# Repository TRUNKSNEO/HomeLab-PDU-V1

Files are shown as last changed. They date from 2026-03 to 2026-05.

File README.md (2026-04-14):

<div align="center">
  Shrike Lab logo
  
  [Website](https://www.shrikelab.co) | [YouTube](https://www.youtube.com/@ShrikeLab)
  
</div>
<p align="center">
  <a href="https://patreon.com/shrikelab">
    
  </a>
  <a href="https://ko-fi.com/shrikelab">
    
  </a>
</p>

# **ShrikeLab PDU V1** - 5 & 10 port USB-C PDUs for 10" and 19" racks
These PSUs are power delivery solutions for micro PC clusters and homelabs that suits either 10" and 19" racks. All variants are built around a Meanwell HRP-300-24 featuring either 5 or 10 USB-C power delivery ports enclosed in sheet metal or 3D printed ABS/ASA housings. 

<div align="center">
  <a
    href="https://www.Shrikelab.co" title="Kits and PCBs available now!">Kits and PCBs available now!
  </a>  
</div>

---

<p float="center">
   
</p>

Mini and micro labs are a great solution for homelabbing, but the power delivery options are often bulky and hard to manage due to the need for an individual power brick per computer.
This project helps fix this by consolidating power delivery for up to 10 65W micro PCs into a single unit that fits in either a 10" or 19" 1U rack. This differs from a conventional multi-port USB PD hub by not needing to re-negotiate any power delivery voltages when a unit is turned off or unplugged, or when the power load across ports changes drastically. Also the packaging is designed specifially for rack mounting, with active cooling and simple power switching.

[**Design and build video here**](https://www.youtube.com/watch?v=8tTG0TBM7ts)

[**Follow-up and testing video here**](https://www.youtube.com/watch?v=Ig7oZpujHtc&t)

<br>

### Features:
- Both 19" and 10" variants
- Up to 10 x 65W USB-C outputs
- 1U Height
- Active cooling
- Sheet metal housing or fully 3D printable
- All variants built around a Meanwell HRP-300-24
- All 3D printed parts fit on a 220x220mm print bed

<br>

### Repo Content:
- **Assembly** - Renders and references for main and sub-assemblies, plus bill of material for each variant
  - **CAD** - CAD files for all varients, universal files and drawings of components
    - **Universal** - Files thats are used for multiple variants
    - 10in_Single
    - 10in_Dual
    - 10in_3D_Modular
    - 10in_3D_Unibody
    - 19in_Single
    - 19in_Dual
    - 19in_Dual_SBS
    - **Blanks** - STP files for customisation
    - **Universal** - STL and STP files that are used for multiple variants
  - **Drawings** - Drawings of components and wiring
    - **Electrical** - Harness pinouts and drawings of electronic components
    -  **Hardware** - Drawings of hardware along with sheet metal engineering drawings
- **IMG** - Images
- **PCB** - PCB gerber manufacturing files

<br>

### Issues:
There's a lot of ground to cover with this repo, so if you find an issue, please raise it with the GitHub issue system and it will get fixed. If you have questions about assembly or any of the variants, please make sure you have read through all the readme content before reaching out to save on time.

### ToDo:
- Export all sheet metal STEP files in 1.2mm thickness for imperial
- Add 40mm fan guide and buck converter writeup

# Variants:
All variants are built around a Meanwell HRP-300-24 and the same PCB. The housings are designed to fit in 1U of space in either a 10in and 19in server rack. 

## 10 Inch - Single:
The original 10" enclosure, a sheet metal body + lid make up the housing, with a 3D printed front and rear. 5 outputs.
<p float="center">
   
</p>
<p float="center">
   
   
</p>

[Bill of materials](https://github.com/Shrike-Lab/MiniLab-PSU/blob/main/ASSEMBLY/README.md#10-inch---single)

<br>

## 10 Inch - 3D Printed - Unibody:
10" printed unibody enclosure, made to be as easy as possible with minimal additional hardware, with the trade-off of being a little harder to print. No inserts required, all bolts thread directly into the print material. Small hatch for attaching button + fan and connecting wiring to PCB.
<p float="center">
   
</p>
<p float="center">
   
   
</p>

[Bill of materials](https://github.com/Shrike-Lab/MiniLab-PSU/blob/main/ASSEMBLY/README.md#10-inch---3d-printed---unibody)

<br>

## 10 Inch - 3D Printed - Modular:
10" printed enclosure, made to be more modular and mod-friendly but requires more M3 inserts and bolts to assebmle. The CAD folder for this variant also includes 'flipped' front and rear STLs that have the mounting tabs swapped, so that the USB-C ports and power intput will face the front of the rack instead of the rear.
<p float="center">
   
</p>
<p float="center">
   
   
</p>

[Bill of materials](https://github.com/Shrike-Lab/MiniLab-PSU/blob/main/ASSEMBLY/README.md#10-inch---3d-printed---modular)

<br>

## 10 Inch - Dual:
10" enclosure for external PSU's. 10 outputs, intended for use with alternative power sources like battery or solar, or for up-cycling external 300W PSUs.
<p float="center">
   
</p>
<p float="center">
   
   
</p>

[Bill of materials](https://github.com/Shrike-Lab/MiniLab-PSU/blob/main/ASSEMBLY/README.md#10-inch---dual)

<br>

## 19 Inch - Single:
19" inch version of 5 output variant. Additional space could be used for cable / tiny-mini-micro storage.
<p float="center">
   
</p>
<p float="center">
   
   
</p>

[Bill of materials](https://github.com/Shrike-Lab/MiniLab-PSU/blob/main/ASSEMBLY/README.md#19-inch---single)

<br>

## 19 Inch - Dual:
19" with 10 outputs from 2 x internal assemblies.
<p float="center">
   
</p>
<p float="center">
   
   
</p>

[Bill of materials](https://github.com/Shrike-Lab/MiniLab-PSU/blob/main/ASSEMBLY/README.md#19-inch---dual)

<br>

## 19 Inch - SBS:
For people that couldn't possibly deal with a power input in the middle of the housing, this version has matching components side-by-side so inputs and outputs can be coordinated easier. One harness will require extending due to the layout.
<p float="center">
   
</p>
<p float="center">
   
   
</p>

[Bill of materials](https://github.com/Shrike-Lab/MiniLab-PSU/blob/main/ASSEMBLY/README.md#19-inch---dual---sbs)

<br>

# Disclaimer:
If you build, modify, or use this project, you do so entirely at your own risk. The author provides these files without any warranty or guarantee of safety, reliability, or fitness for any particular purpose, and accepts no liability for any damage, injury, loss, or other consequences resulting from their use.

# License:
This project is licensed under the Creative Commons Attribution-NonCommercial-ShareAlike 4.0 International License.

You may use, share, and modify the files in this repository for personal, non-commercial purposes, provided you give appropriate attribution and distribute any derivatives under the same license.

Commercial use is not permitted without separate written permission.

Editable source design files may not be provided; this repository may include manufacturing or export files only.

Learn more [here.](https://creativecommons.org/licenses/by-nc-sa/4.0/deed.en)

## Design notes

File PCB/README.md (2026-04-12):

# PCB:
All variants use the same 2 layer 1.6mm thick PCB. This folder contains production files that can be uploaded to a PCB service for manufacturing, JLCPCB is my go-to. PCB assembly is recommended unless you have capability to do SMD soldering with either a hot air station or reflow oven.
There is currently no option for a through-hole variant because the tranistor does not come in a TH package.

**Parameters for PCB manufacturing:**
- 2 Oz copper trace weight - This is a must for current rating
- 1.6mm PCB thickness

<br>

### PCB Notes:
- You can use either an LM2596S or and MP1584EN. Just move the mounting headers to the corresponding holes.
- Connectors J19, J20, J21, J22 are optional. Either used for additional power output, or testing.
- After assembly, set fan header output voltage **before** plugging any fans in.

<br>

### Power Delivery Modules:
THe board assembly contains 5 USB-C power delivery modules that are based on an XPM52C with the following power profiles.

12V/3A, 15V/3A, 20V/3.25A

**Low Power PDO:** 5V/3A, 9V/3A, 12V/2.5A, 20V/1.5A

**High Power PDO:** 5V/3A, 9V/3A, 12V/3A

There's an interesting article [here](https://mysku.club/blog/aliexpress/101076.html) (is in Russian so will need translating) that goes over the thermal performance of the power delivery chips at 65W.

<p float="center">
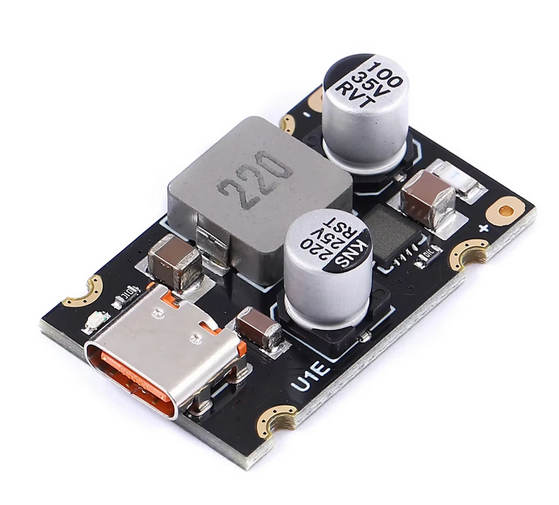
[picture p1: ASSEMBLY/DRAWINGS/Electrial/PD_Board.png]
   
</p>

### Buck Converter:
To power the 40mm chassis fans the main 24V rail needs to be stepped down to 12V. This can be done with either an LM2596S or MP1584EN, on the PCB there's header holes and labels for both. The LM2596S is much more popular, but the MP1584EN is newer and has less EMC. MP1584EN comes in multiple variants, **make sure to get the variable one so you're able to tune the fan voltage**.

<p float="center">
   
   
</p>

### Wiring:
There are two harnesses per set of internal electronics, one for main power and one for the button. The drawings can be found [here](https://github.com/Shrike-Lab/MiniLab-PSU/tree/main/ASSEMBLY/DRAWINGS/Electrial).

- **I would highly recommend you double check the pinout of your latching button before wiring it up, as they can differ from brand to brand.**

| Part | Harness | Quantity Per Assembly | Link |
| --- | --- | --- | --- |
| Ring spade | 24V Power | 9 | https://www.digikey.com/en/products/detail/molex/0193240008/3884473 |
| PCB Connector | 24V Power & Button | 2 | https://www.digikey.com/en/products/detail/molex/0039012060/61379?s=N4IgTCBcDaIOoFkDMB2ADGAtAOQCIgF0BfIA |
| Crimp | 24V Power & Button | 12 | https://www.digikey.com/en/products/detail/molex/0039000039/61448?s=N4IgTCBcDaIOoFkwFYAMBGAtAOQCIgF0BfIA |
| IEC Terminals | Mains Power | 7 | https://www.digikey.com/en/products/detail/molex/0190030011/279039 |

<br>

## PCB Component BOM:

| Type | Key | Value | Footprint | Quantity | Component | Commment |
| --- | --- | --- | --- | --- | --- | --- |
| Capacitor | C1,C2,C5,C6,C7,C8,C9 | 470uF | THT-CP_Radial_D10 | 6 | - | - |
| Capacitor | C3 | 1uF | 1206 | 1 | - | - |
| Capacitor | C4 | 220nF | 0603 | 1 | - | - |
| Capacitor | C10,C11,C12,C13,C14  | 1uF | 1206 | 5 | - | - |
| Capacitor | C15,C16,C17,C18,C19  | .1uF | 0603 | 5 | - | - |
| Resistor  | R1 | 4.7k | 1206 | 1 | - | - |
| Resistor  | R2 | 47k | 0603 | 1 | - | - |
| Resistor  | R3 | 100 | 0603 | 1 | - | - |
| Resistor  | R4 | 100k | 0603 | 1 | - | - |
| Diode | D1,D2,D3,D4,D5 | SMBJ26A | D_SMB | 5 | - | - |
| Diode | D6 | SMCJ26A | D_SMC | 1 | - | - |
| Diode | D7 | Zener | SOD-123 | 1 | BZT52C12 | - |
| Fuse | F1 | 15A | 2410 | 1 | 0451020.MRL | - |
| Fuse | F2,F3,F4F5,F6 | 3A | 1206 | 5 | 1206FA-4A | - |
| Connector | J1,J2 | - | Molex_5569-06A2 | 2 | Molex_5569-06A2 | Power and button |
| Connector | J13,J14,J15,J16 | - | 1x01_2.54mm | 4 | 1x01_2.54mm | Buck converter |
| Connector | J17,J18 | - | Molex_2272031 | 2 | Molex_2272031 | Fans |
| Connector | J19,J21,J22 | - | 1x02_2.54mm | 3 | 1x02_2.54mm | Debug |
| Connector | J20 | - | JST_PH-K_1x02 | 1 | JST_PH-K_1x02 | PSU sense |
| Mosfet | Q1 | - | TO-263-2L | 1 | NCEP40PT15D | - |

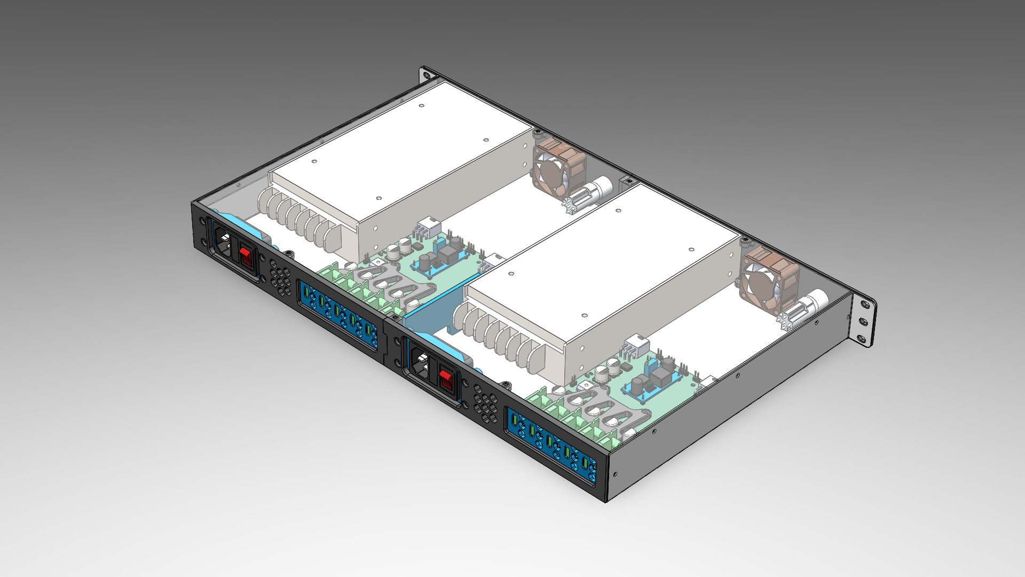
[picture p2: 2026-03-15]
Images/19in-Dual/19in-Dual-C.png

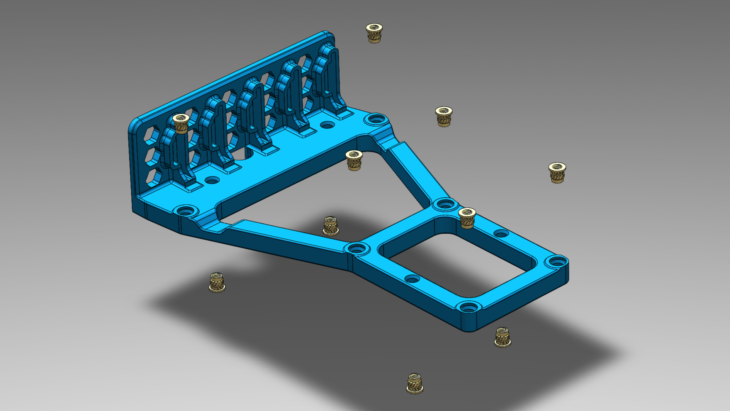
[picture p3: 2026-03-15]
Images/General/PCB-Bracket.png

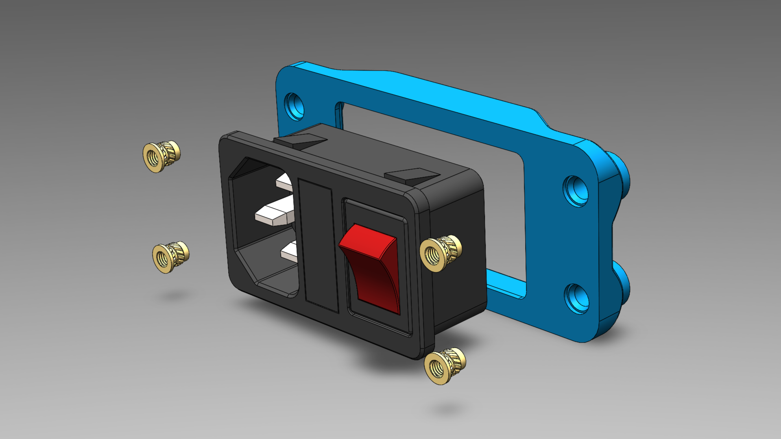
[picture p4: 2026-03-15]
Images/General/IEC-Bracket.png

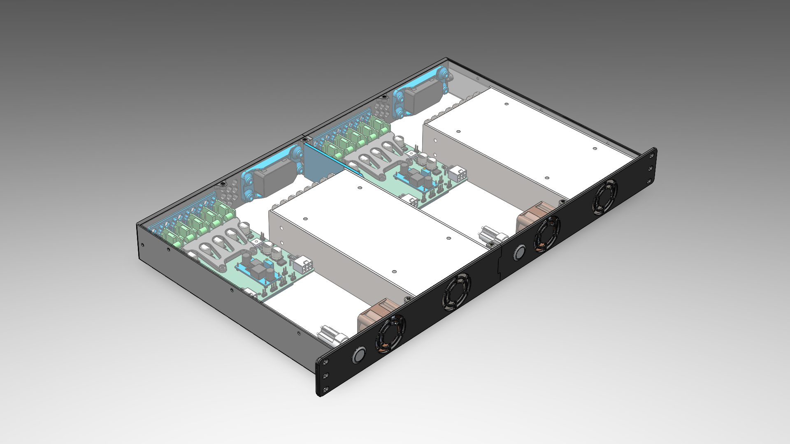
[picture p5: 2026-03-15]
Images/19in-Dual/19in-Dual-B.png

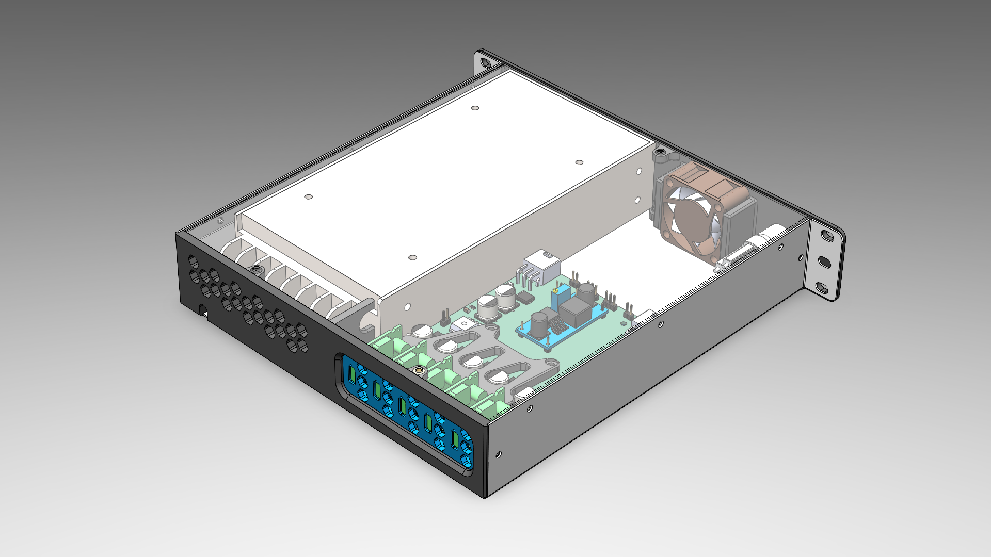
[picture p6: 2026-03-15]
Images/10in-Single/10in-Single-C.png

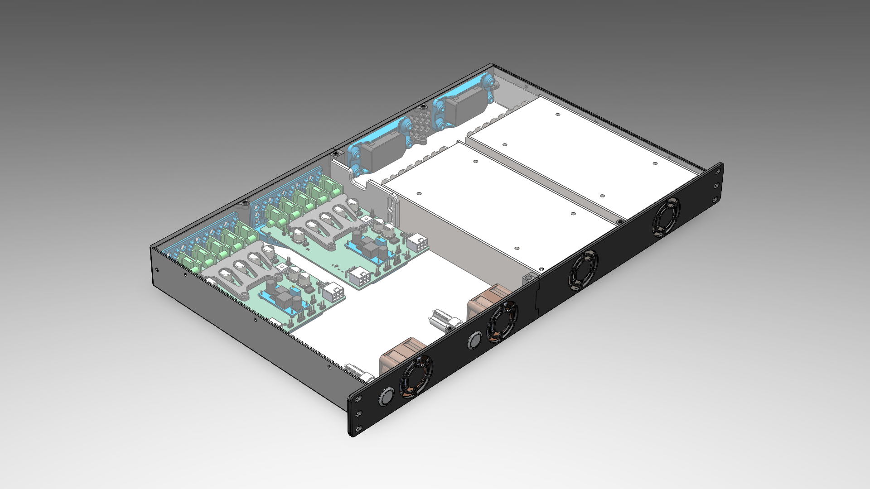
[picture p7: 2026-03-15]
Images/19in-SBS/19in-SBS-B.png

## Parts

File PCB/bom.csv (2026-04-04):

Designator | Footprint | Quantity | Value | LCSC Part #
C1, C2, C5, C6, C7, C8, C9 | CP_Elec_10x10 | 7 | 470uF
C10, C11, C12, C13, C14, C3 | 1206 | 6 | 1uF
C15, C16, C17, C18, C19 | 0603 | 5 | .1uF
C4 | 0603 | 1 | 220nF
D1, D2, D3, D4, D5 | D_SMB | 5 | SMBJ26A
D6 | D_SMB-SMC_Universal_Handsoldering | 1 | SMCJ26A
D7 | D_SOD-123 | 1 | 12V Zener
F1 | 2410 Fuse | 1 | Fuse_0
F2 | 1206 | 1 | Fuse_1
F3 | 1206 | 1 | Fuse_2
F4 | 1206 | 1 | Fuse_3
F5 | 1206 | 1 | Fuse_4
F6 | 1206 | 1 | Fuse_5
J1 | Molex_Mini-Fit_Jr_5569-06A2_2x03_P4.20mm_Horizontal | 1 | Power_Input
J10 | PinHeader_1x01_P2.54mm_Vertical | 1 | 3_Neg
J11 | PinHeader_1x01_P2.54mm_Vertical | 1 | 4_Neg
J12 | PinHeader_1x01_P2.54mm_Vertical | 1 | 5_Neg
J17 | PinHeader_1x03_P2.54mm_Vertical | 1 | Fan_1
J18 | PinHeader_1x03_P2.54mm_Vertical | 1 | Fan_2
J2 | Molex_Mini-Fit_Jr_5569-06A2_2x03_P4.20mm_Horizontal | 1 | Button_Input
J20 | JST_PH_B2B-PH-K_1x02_P2.00mm_Vertical | 1 | Sens
J3 | PinHeader_1x01_P2.54mm_Vertical | 1 | 1_Pos
J4 | PinHeader_1x01_P2.54mm_Vertical | 1 | 2_Pos
J5 | PinHeader_1x01_P2.54mm_Vertical | 1 | 3_Pos
J6 | PinHeader_1x01_P2.54mm_Vertical | 1 | 4_Pos
J7 | PinHeader_1x01_P2.54mm_Vertical | 1 | 5_Pos
J8 | PinHeader_1x01_P2.54mm_Vertical | 1 | 1_Neg
J9 | PinHeader_1x01_P2.54mm_Vertical | 1 | 2_Neg
Q1 | TO-263-3_TabPin2 | 1 | NCEP40PT15D | IRF9540NPBF
R1 | 1206 | 1 | 4.7k
R2 | 0603 | 1 | 47k
R3 | 0603 | 1 | 100
R4 | 0603 | 1 | 100k

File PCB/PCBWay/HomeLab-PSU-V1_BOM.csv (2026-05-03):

Designator | Quantity | Value | Footprint | Package | MPN | DNP | Mount_Type | Description | Digi-Key_PN | Category | Family | DK_Datasheet_Link | DK_Detail_Page | Description_1 | Manufacturer | Status
C1, C2, C5, C6, C7, C8, C9 | 7 | 470uF | CP_Elec_10x10 |  |  |  | smt | Unpolarized capacitor
C10, C11, C12, C13, C14, C3 | 6 | 1uF | C_1206_3216Metric_Pad1.33x1.80mm_HandSolder |  |  |  | smt | Unpolarized capacitor
C15, C16, C17, C18, C19 | 5 | .1uF | C_0603_1608Metric_Pad1.08x0.95mm_HandSolder |  |  |  | smt | Unpolarized capacitor
C4 | 1 | 220nF | C_0603_1608Metric_Pad1.08x0.95mm_HandSolder |  |  |  | smt | Unpolarized capacitor
D1, D2, D3, D4, D5 | 5 | SMBJ26A | D_SMB |  |  |  | smt | 20V 2A Schottky Barrier Rectifier Diode, SMB
D6 | 1 | SMCJ26A | D_SMB-SMC_Universal_Handsoldering |  |  |  | smt | 20V 2A Schottky Barrier Rectifier Diode, SMB
D7 | 1 | 12V Zener | D_SOD-123 |  |  |  | smt | Zener diode
F1 | 1 | Fuse_0 | 2410 Fuse |  |  |  | tht | Fuse
F2 | 1 | Fuse_1 | Fuse_1206_3216Metric_Pad1.42x1.75mm_HandSolder |  |  |  | smt | Fuse
F3 | 1 | Fuse_2 | Fuse_1206_3216Metric_Pad1.42x1.75mm_HandSolder |  |  |  | smt | Fuse
F4 | 1 | Fuse_3 | Fuse_1206_3216Metric_Pad1.42x1.75mm_HandSolder |  |  |  | smt | Fuse
F5 | 1 | Fuse_4 | Fuse_1206_3216Metric_Pad1.42x1.75mm_HandSolder |  |  |  | smt | Fuse
F6 | 1 | Fuse_5 | Fuse_1206_3216Metric_Pad1.42x1.75mm_HandSolder |  |  |  | smt | Fuse
J1 | 1 | Power_Input | Molex_Mini-Fit_Jr_5569-06A2_2x03_P4.20mm_Horizontal |  |  |  | tht | Generic connector, double row, 02x03, counter clockwise pin numbering scheme (similar to DIP package numbering), script generated (kicad-library-utils/schlib/autogen/connector/)
J17 | 1 | Fan_1 | PinHeader_1x03_P2.54mm_Vertical |  |  |  | tht | Generic connector, single row, 01x03, script generated
J18 | 1 | Fan_2 | PinHeader_1x03_P2.54mm_Vertical |  |  |  | tht | Generic connector, single row, 01x03, script generated
J19 | 1 | Fan_V | PinSocket_1x02_P2.54mm_Vertical |  |  |  | tht | Generic connector, single row, 01x02, script generated
J2 | 1 | Button_Input | Molex_Mini-Fit_Jr_5569-06A2_2x03_P4.20mm_Horizontal |  |  |  | tht | Generic connector, double row, 02x03, counter clockwise pin numbering scheme (similar to DIP package numbering), script generated (kicad-library-utils/schlib/autogen/connector/)
J20 | 1 | Sens | JST_PH_B2B-PH-K_1x02_P2.00mm_Vertical |  |  |  | tht | Generic connector, single row, 01x02, script generated
J21, J22 | 2 | 24V | PinSocket_1x02_P2.54mm_Vertical |  |  |  | tht | Generic connector, single row, 01x02, script generated
Q1 | 1 | NCEP40PT15D | TO-263-3_TabPin2 |  | IRF9540NPBF |  | smt | MOSFET P-CH 100V 23A TO-220AB | IRF9540NPBF-ND | Discrete Semiconductor Products | Transistors - FETs, MOSFETs - Single | https://www.infineon.com/dgdl/irf9540npbf.pdf?fileId=5546d462533600a401535611cfa21dc8 | /product-detail/en/infineon-technologies/IRF9540NPBF/IRF9540NPBF-ND/812088 | MOSFET P-CH 100V 23A TO-220AB | Infineon Technologies | Active
R1 | 1 | 4.7k | R_1206_3216Metric |  |  |  | smt | Resistor
R2 | 1 | 47k | R_0603_1608Metric |  |  |  | smt | Resistor
R3 | 1 | 100 | R_0603_1608Metric |  |  |  | smt | Resistor
R4 | 1 | 100k | R_0603_1608Metric |  |  |  | smt | Resistor

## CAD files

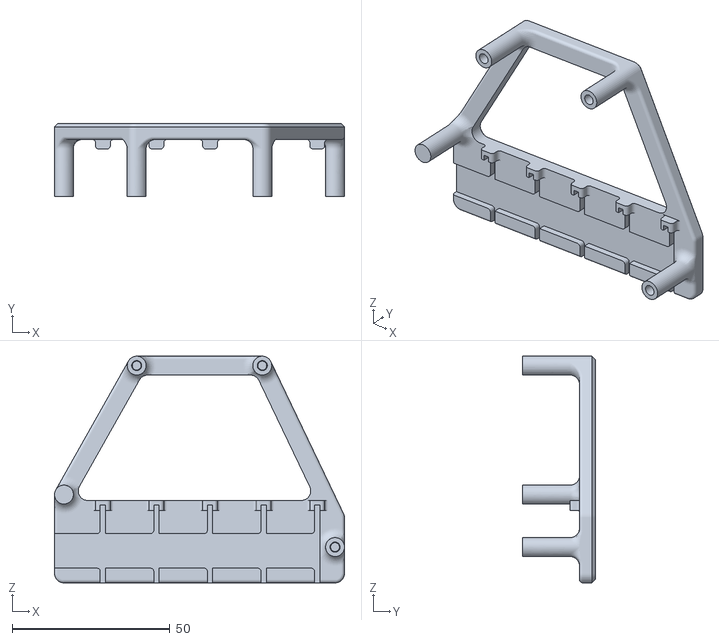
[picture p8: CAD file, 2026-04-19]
ASSEMBLY/CAD/Universal/Assembly_Bracket.STL
92.0 x 23.0 x 71.9

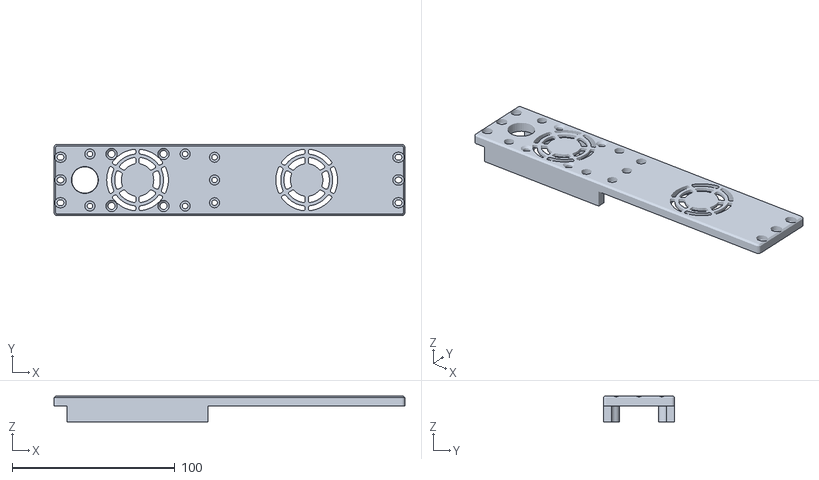
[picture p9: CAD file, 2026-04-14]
ASSEMBLY/CAD/10in_3D_Modular/10in_3D-Front-FLIPPED.STL
216.0 x 44.0 x 16.0

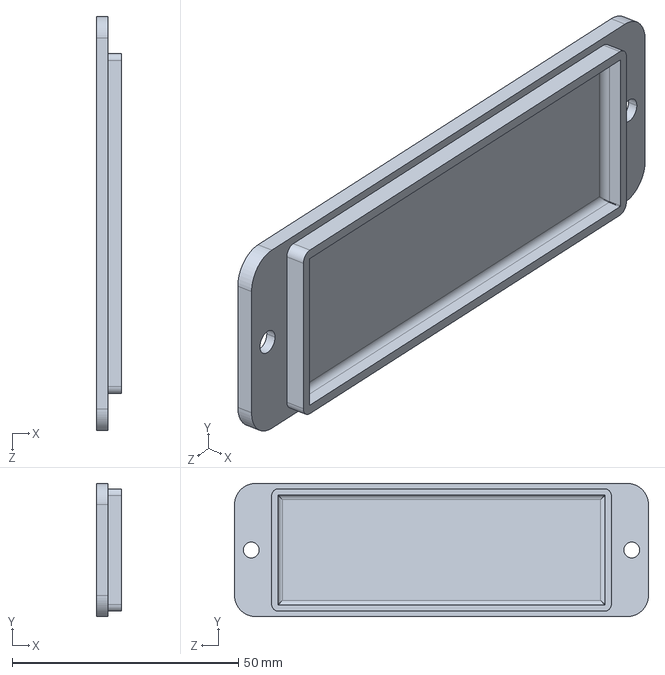
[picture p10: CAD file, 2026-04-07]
ASSEMBLY/CAD/10in_3D_Unibody/10in_Uni-SidePanel.STEP
5.50 x 29.4 x 91.4 mm

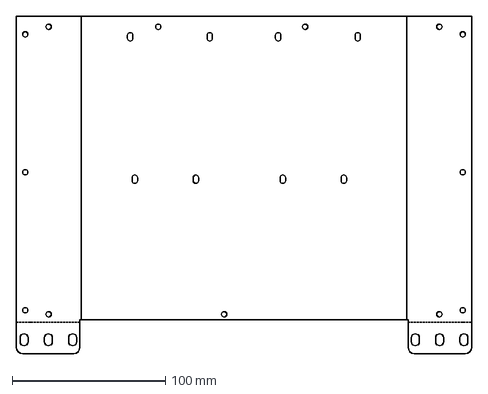
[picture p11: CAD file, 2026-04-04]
ASSEMBLY/CAD/10in_Dual/Metal_Tray_Dual.DXF
297.1 x 220.1 mm

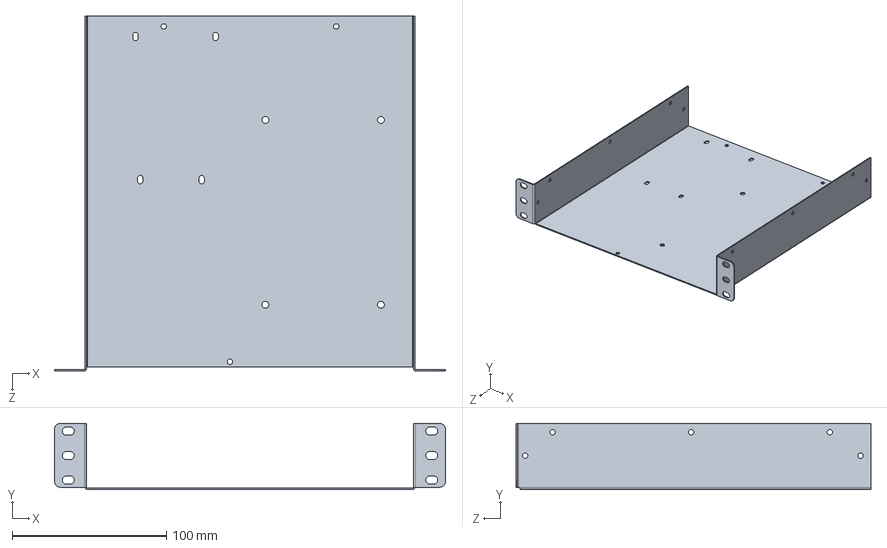
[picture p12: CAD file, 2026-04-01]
ASSEMBLY/CAD/10in_Single/Metal_Tray.STEP
254.0 x 43.0 x 230.5 mm

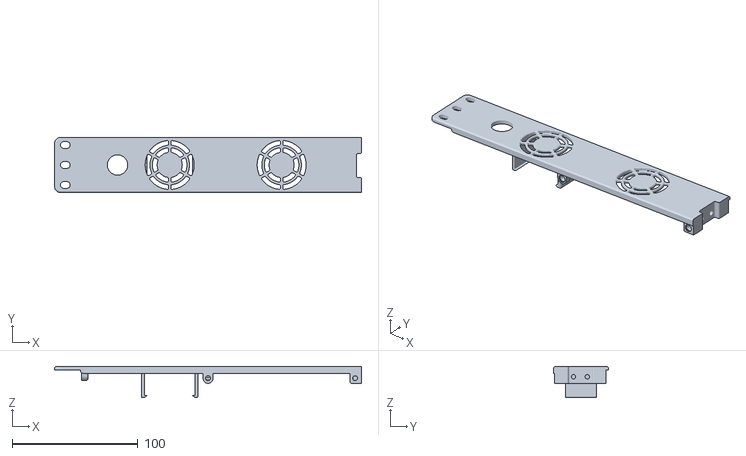
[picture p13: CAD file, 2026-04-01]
ASSEMBLY/CAD/19in_Dual/19in_Dual-Front_2.stl
244.1 x 44.0 x 24.7

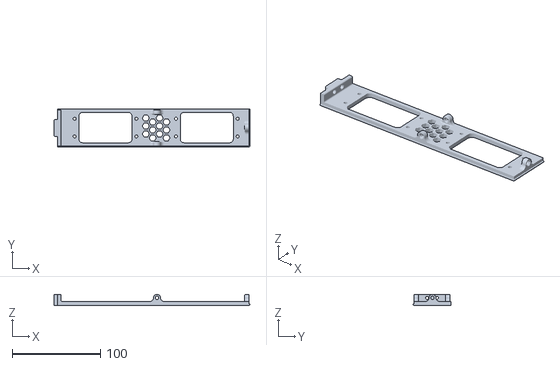
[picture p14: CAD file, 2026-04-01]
ASSEMBLY/CAD/19in_Dual_SBS/19in_Dual_SBS-Back_1.STL
222.4 x 43.0 x 12.8

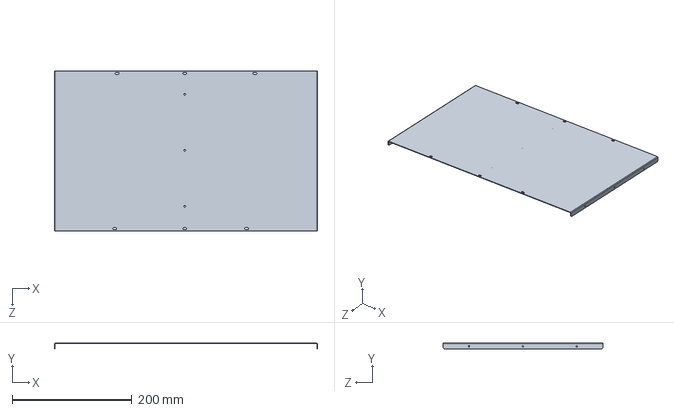
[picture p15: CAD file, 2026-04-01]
ASSEMBLY/CAD/19in_Single/19in_Single-Lid.stp
438.7 x 10.0 x 267.1 mm

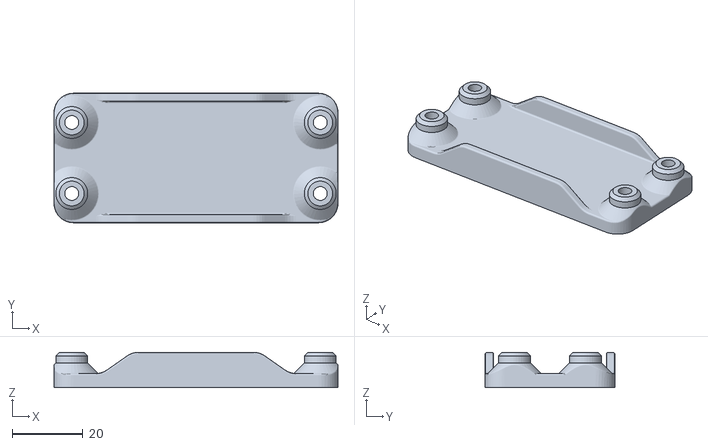
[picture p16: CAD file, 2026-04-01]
ASSEMBLY/CAD/Blanks/IEC_Bracket-BLANK.STL
80.0 x 36.5 x 10.00

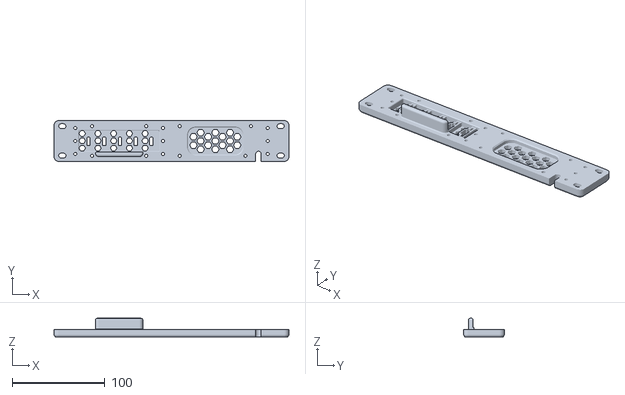
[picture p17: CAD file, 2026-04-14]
ASSEMBLY/CAD/10in_3D_Modular/10in_3D-Back-FLIPPED.STL
254.0 x 44.0 x 20.0

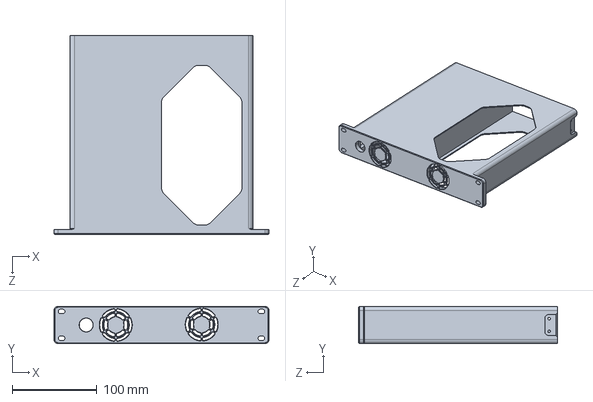
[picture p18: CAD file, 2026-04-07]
ASSEMBLY/CAD/10in_3D_Unibody/10in_Uni-Body.STEP
254.0 x 44.0 x 235.0 mm

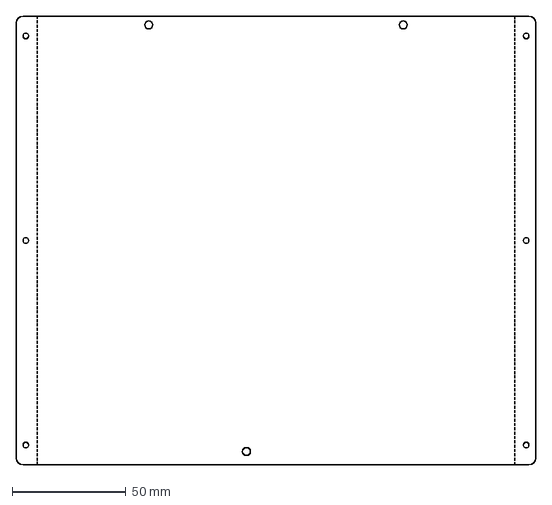
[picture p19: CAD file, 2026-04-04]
ASSEMBLY/CAD/10in_Dual/Metal_Lid-Short.DXF
228.6 x 197.5 mm

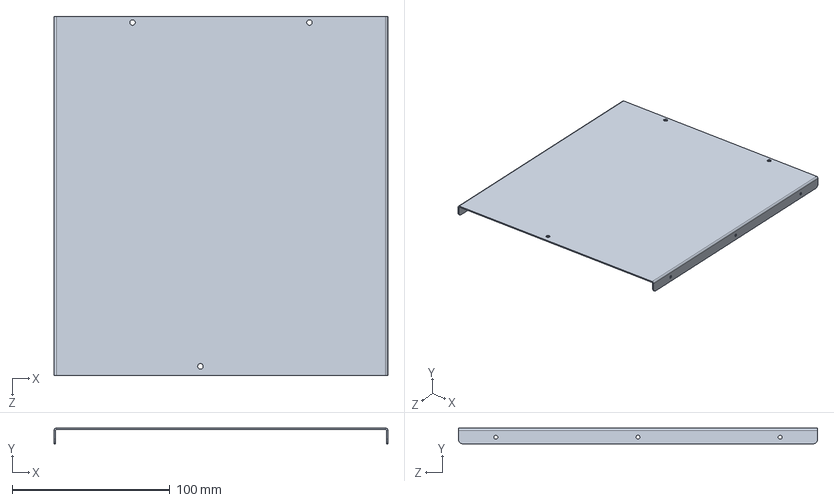
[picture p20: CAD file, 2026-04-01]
ASSEMBLY/CAD/10in_Single/Metal_Lid.STEP
211.5 x 10.0 x 227.5 mm

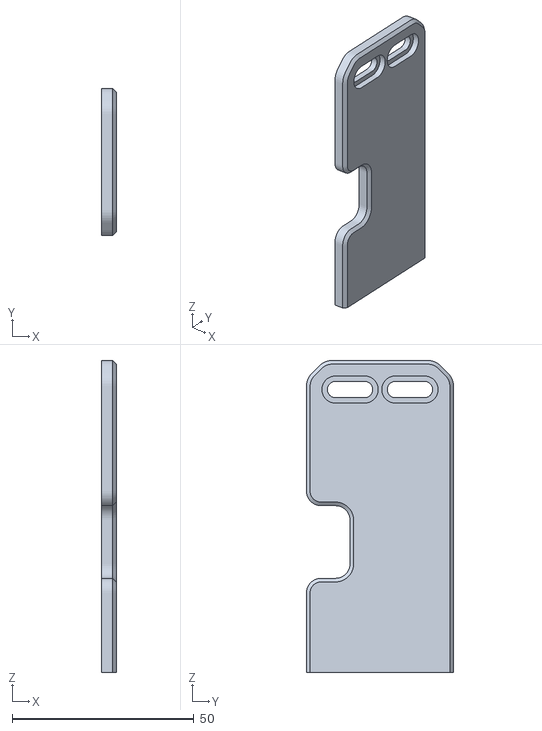
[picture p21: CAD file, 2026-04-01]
ASSEMBLY/CAD/19in_Dual/19in_Dual-Divider.STL
4.00 x 40.5 x 86.0

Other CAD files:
ASSEMBLY/CAD/19in_Dual_SBS/19in_Dual_SBS-Front_1.STL
ASSEMBLY/CAD/19in_Single/19in_Single-Front_2.stl
ASSEMBLY/CAD/Blanks/IEC_Bracket.STEP
ASSEMBLY/CAD/Universal/Reinforcement_Bracket.STL
ASSEMBLY/CAD/10in_3D_Modular/10in_3D-Back.stl
ASSEMBLY/CAD/10in_3D_Modular/10in_3D-Bottom_1.stl
ASSEMBLY/CAD/10in_3D_Modular/10in_3D-Bottom_2.stl
ASSEMBLY/CAD/10in_3D_Modular/10in_3D-Front.stl
ASSEMBLY/CAD/10in_3D_Modular/10in_3D-Left.stl
ASSEMBLY/CAD/10in_3D_Modular/10in_3D-Middle.stl
ASSEMBLY/CAD/10in_3D_Modular/10in_3D-Right.stl
ASSEMBLY/CAD/10in_3D_Modular/10in_3D-Top_1.stl
ASSEMBLY/CAD/10in_3D_Modular/10in_3D-Top_2.stl
ASSEMBLY/CAD/10in_3D_Unibody/10in_Uni-Body.STL
ASSEMBLY/CAD/10in_3D_Unibody/10in_Uni-SidePanel.STL
ASSEMBLY/CAD/10in_3D_Unibody/10in_Uni-Tray.STEP
ASSEMBLY/CAD/10in_3D_Unibody/10in_Uni-Tray.STL
ASSEMBLY/CAD/10in_Dual/10in_Dual-Front.stl
ASSEMBLY/CAD/10in_Dual/10in_Dual-Lid.stp
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

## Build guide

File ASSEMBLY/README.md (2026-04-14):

# Assembly:
This section contains the bill of materials for each variant, as well as renders and exploded views of the sub-assemblies.

- All trays mount to the racks with M5 hardware
- For 3D printing all files have been exported as an STL
- Blank parts have been exported as an STP to help editing
- Metal parts are exported as an STP
- As the metal housing lids require tapping, there is an engineering drawing in the [drawings folder](https://github.com/Shrike-Lab/MiniLab-PSU/tree/main/ASSEMBLY/DRAWINGS/Hardware)
- Highly recommended to order extra insert and bolt hardware

**All variants contain the following components:**
| Component |Link/Location | Source |
| --- |--- | --- |
| PDU PCB Ver 1.0 | [Drawing](https://github.com/Shrike-Lab/HomeLab-PDU-V1/blob/main/PCB/Minilab_PDU_V1.zip) | Shrikelab kit or buy PCB manufacturing service|
| 16mm Button | [Drawing](https://github.com/Shrike-Lab/HomeLab-PDU-V1/blob/main/ASSEMBLY/DRAWINGS/Electrial/Harness-Button.pdf)  | Shrikelab kit or buy online |
| Button harness | [Drawing](https://github.com/Shrike-Lab/HomeLab-PDU-V1/blob/main/ASSEMBLY/DRAWINGS/Electrial/Harness-Button.pdf)| Shrikelab kit or comes with button |
| Power harness | [Drawing](https://github.com/Shrike-Lab/HomeLab-PDU-V1/blob/main/ASSEMBLY/DRAWINGS/Electrial/Harness-Power.pdf) | Shrikelab kit or DIY |
| 40mm cooling fan | - | - |

### Drawings of components can be found here:
**Hardware:**
| Component |Link/Location | Source |
| --- |--- | --- |
| M3 Low Profile Bolt | [Drawing](https://github.com/Shrike-Lab/HomeLab-PDU-V1/blob/main/ASSEMBLY/DRAWINGS/Hardware/Bolt-LowProfile.png) | - | 
| M3 Cap Head Bolt | [Drawing](https://github.com/Shrike-Lab/HomeLab-PDU-V1/blob/main/ASSEMBLY/DRAWINGS/Hardware/Bolt-CapHead.png) | - |
| M4 Low Profile Bolt | [Drawing](https://github.com/Shrike-Lab/HomeLab-PDU-V1/blob/main/ASSEMBLY/DRAWINGS/Hardware/Bolt-LowProfile.png) | - |
| M4 Cap Head Bolt | [Drawing](https://github.com/Shrike-Lab/HomeLab-PDU-V1/blob/main/ASSEMBLY/DRAWINGS/Hardware/Bolt-CapHead.png) | - | 
| M3 Insert | [Drawing](https://github.com/Shrike-Lab/HomeLab-PDU-V1/blob/main/ASSEMBLY/DRAWINGS/Hardware/M3-Insert.pdf) | - |

**Electrical:**
| Component |Link/Location | Source |
| --- |--- | --- |
| MP1584EN | [Drawing](https://github.com/Shrike-Lab/HomeLab-PDU-V1/blob/main/ASSEMBLY/DRAWINGS/Electrial/Buck_Board.png) | Online (Search term: MP1584EN Buck Converter)|
| Heatsink | [Drawing](https://github.com/Shrike-Lab/HomeLab-PDU-V1/blob/main/ASSEMBLY/DRAWINGS/Electrial/Heatsink.png) | Online (Search term: 10x10x10mm Aluminium headsink) |
| PD Board | [Drawing](https://github.com/Shrike-Lab/HomeLab-PDU-V1/blob/main/ASSEMBLY/DRAWINGS/Electrial/PD_Board.png) | Online (Search term: DC to 65w fast charging USB-C board) |

<br>

## Sub-Assemblies:
There are two assemblies that are shared between the variants using a sheet metal housing.

### PCB Tray:
This PCB tray makes soldering the daughter boards easier, and allows the board to be installed and removed from the chassis easier.
<p float="center">
   
  
  
</p>

| Component | Quantity | Link/Location |
| --- | --- | --- |
| PDU PCB Ver 1.0 | 1 | [Gerber](https://github.com/Shrike-Lab/HomeLab-PDU-V1/tree/main/PCB) | 
| PCB Tray | 1 | [STL](https://github.com/Shrike-Lab/MiniLab-PSU/blob/main/ASSEMBLY/CAD/Universal/PCB_Tray.stl) | 
| USB-C 65W PD Board | 5 | [Image](https://github.com/Shrike-Lab/MiniLab-PSU/blob/main/ASSEMBLY/DRAWINGS/Electrial/Heatsink.png) | 
| Heatsink | 5 | [Drawing](https://github.com/Shrike-Lab/MiniLab-PSU/blob/main/ASSEMBLY/DRAWINGS/Electrial/Heatsink.png) | 
| PCB Reinforement | 1 | [STL](https://github.com/Shrike-Lab/MiniLab-PSU/blob/main/ASSEMBLY/CAD/Universal/Reinforcement_Bracket.stl) | 
| Buck Converter | 1 | [Image](https://github.com/Shrike-Lab/MiniLab-PSU/blob/main/ASSEMBLY/DRAWINGS/Electrial/Buck_Board.png) | 

<br>

### IEC Plug:
Due to the extra depth allowed on full racks, all 19" variants use the IEC plug sub-assembly to allow for a detachable cable.
<p float="center">
   
</p>

| Component | Quantity | Link/Location |
| --- | --- | --- |
| IEC Socket | 1 | [Digikey part link](https://www.digikey.com/en/products/detail/adam-tech/IEC-GS-1-100/9831135) |
| IEC Bracket | 1 | [STL](https://github.com/Shrike-Lab/MiniLab-PSU/blob/main/ASSEMBLY/CAD/Universal/IEC_Bracket.stl) |
| IEC Spade Terminals | 7 | [Digikey part link](https://www.digikey.com/en/products/detail/molex/0190030011/279039) |
| IEC Fuse | 1 | [Digikey part link](https://www.digikey.com/en/products/detail/littelfuse-inc/0232008-MXP/778029) |

<br>

### PCB Assembly Bracket:
If additional assitance is required during assembly, this bracket (Yellow) can be printed to hold the boards in place. It's then removed and replaced with the reinforcment bracket when the assembly is installed into a chassis.
<p float="center">
   
</p>

<br>

# Variant BOMs:

## 10 Inch - Single:
<p float="center">
   
</p>

#### **Sub-Assemblies:**
| Assembly | Quantity |
| --- | --- |
| [PCB Tray](README.md#pcb-tray) | 1 |

#### **Housing:**
| Item  | File Name | Material | Quantity |
| ----- | --- | --- | --- |
| Tray  | 10in_Single-Tray.stp  | Sheel Metal | 1 |
| Lid | 10in_Single-Lid.stp | Sheel Metal | 1 |
| Front | 10in_Single-Front.stl | 3D Print (ABS/ASA) | 1 |
| Back  | 10in_Single-Back.stl  | 3D Print (ABS/ASA) | 1 |
[Housing files are located here](https://github.com/Shrike-Lab/MiniLab-PSU/tree/main/ASSEMBLY/CAD/10in_Single)

#### **Hardware**
| Item | Length | Quantity |
| --- | --- | --- |
| M3 Low Profile Bolt | 5mm | 24 |
| M3 Low Profile Bolt | 8mm | 2 |
| M3 Plastic Washer | - | 4 |
| M4 Low Profile Bolt | 5mm | 4 |
| M3 Insert | - | 20 |

<br>

## 10 Inch - 3D Printed - Unibody:
<p float="center">
   
</p>

#### **Sub-Assemblies:**
This variant contains no sub-assemblies still requires the [PCB reinforcement bracket](https://github.com/Shrike-Lab/MiniLab-PSU/tree/main/ASSEMBLY/CAD/Universal/Reinforcement_Bracket.stl)

#### **Housing:**
| Item | File Name | Material | Quantity |
| --- | --- | --- | --- |
| Body | 10in_Uni-Body.stl  | 3D Print (ABS/ASA) | 1 |
| Tray | 10in_Uni-Tray.stl  | 3D Print (ABS/ASA) | 1 |
| Side Panel | 10in_Uni-SidePanel | 3D Print (ABS/ASA) | 1 |
[Housing files are located here](https://github.com/Shrike-Lab/MiniLab-PSU/tree/main/ASSEMBLY/CAD/10in_3D_Unibody)

#### **Hardware**
| Item | Length | Quantity |
| --- | --- | --- |
| M3 Low Profile Bolt | 5mm | 6 |
| M3 Low Profile Bolt | 8mm | 2 |
| M3 Plastic Washer | - | 4 |
<br>

## 10 Inch - 3D Printed - Modular:
<p float="center">
   
</p>

#### **Sub-Assemblies:**
This variant contains no sub-assemblies still requires the [PCB reinforcement bracket](https://github.com/Shrike-Lab/MiniLab-PSU/tree/main/ASSEMBLY/CAD/Universal/Reinforcement_Bracket.stl)

#### **Housing:**
| Item | File Name | Material | Quantity |
| --- | --- | --- | --- |
| Front | 10in_Mod-Front.stl | 3D Print (ABS/ASA) | 1 | 
| Rear | 10in_Mod-Rear.stl | 3D Print (ABS/ASA) | 1 | 
| Left | 10in_Mod-Left.stl | 3D Print (ABS/ASA) | 1 | 
| Right | 10in_Mod-Right.stl | 3D Print (ABS/ASA) | 1 | 
| Middle | 10in_Mod-Middle.stl | 3D Print (ABS/ASA) | 1 | 
| Top_1 | 10in_Mod-Top_1.stl | 3D Print (ABS/ASA) | 1 | 
| Top_2 | 10in_Mod-Top_2.stl | 3D Print (ABS/ASA) | 1 | 
| Bottom_1 | 10in_Mod-Bottom_1.stl | 3D Print (ABS/ASA) | 1 | 
| Bottom_2 | 10in_Mod-Bottom_2.stl | 3D Print (ABS/ASA) | 1 | 
[Housing files are located here](https://github.com/Shrike-Lab/MiniLab-PSU/tree/main/ASSEMBLY/CAD/10in_3D_Modular)

#### **Hardware**
| Item | Length | Quantity |
| --- | --- | --- |
| M3 Cap Head Bolt | 8mm | 28 |
| M3 Cap Head Bolt | 16mm | 4 | 
| M3 Insert | - | 30 | 
| M4 Cap Head Bolt | 5mm | 7 |  
| M4 Low Profile Bolt | 3mm | 1 | 
| M3 Low Profile Bolt | 5mm | 2 |
| Plastic Washer | - | 2 |

<br>

## 10 Inch - Dual:
<p float="center">
   
</p>

#### **Sub-Assemblies:**
| Assembly | Quantity |
| --- | --- |
| [PCB Tray](README.md#pcb-tray) | 2 |

#### **Housing:**
| Item  | File Name | Material | Quantity |
| ----- | --- | --- | --- |
| Tray  | 10in_Dual-Tray.stp  | Sheel Metal | 1 |
| Lid | 10in_Dual-Lid.stp | Sheel Metal | 1 |
| Front | 10in_Dual-Front.stl | 3D Print (ABS/ASA) | 1 |
| Back  | 10in_Dual-Back.stl  | 3D Print (ABS/ASA) | 1 |
[Housing files are located here](https://github.com/Shrike-Lab/MiniLab-PSU/tree/main/ASSEMBLY/CAD/10in_Dual)

#### **Hardware**
| Item | Length | Quantity |
| --- | --- | --- |
| M3 Low Profile Bolt | 5mm | 32 |
| M3 Low Profile Bolt | 8mm | 4 |
| M3 Plastic Washer | - | 8 |
| M3 Insert | - | 30 |

<br>

## 19 Inch - Single:
<p float="center">
   
</p>

#### **Sub-Assemblies:**
| Assembly | Quantity |
| --- | --- |
| [PCB Tray](README.md#pcb-tray) | 1 |
| [IEC Plug](README.md#iec-plug) | 1 |

#### **Housing:**
| Item | File Name | Material | Quantity |
| --- | --- | --- | --- |
| Tray | 19in_Single-Tray.stp | Sheel Metal | 1 |
| Lid | 19in_Single-Lid.stp | Sheel Metal | 1 |
| Front-1 | 19in_Single-Front_1.stl | 3D Print (ABS/ASA) | 1 |
| Front-2 | 19in_Single-Front_2.stl | 3D Print (ABS/ASA) | 1 |
| Back-1  | 19in_Single-Back_1.stl  | 3D Print (ABS/ASA) | 1 |
| Back-2  | 19in_Single-Back_2.stl  | 3D Print (ABS/ASA) | 1 |
| Interal | 19in_Single-Internal.stl | 3D Print (ABS/ASA) | 1 |
| Divider | 19in_Single-Divider.stl | 3D Print (ABS/ASA) | 1 |

[Housing files are located here](https://github.com/Shrike-Lab/MiniLab-PSU/tree/main/ASSEMBLY/CAD/19in_Single)

#### **Hardware**
| Item | Length | Quantity |
| --- | --- | --- |
| M3 Low Profile Bolt | 5mm | 36 |
| M3 Plastic Washer | - | 4 |
| M3 Insert | - | 40 |
| M4 Low Profile Bolt | 5mm | 4 |
| M3 Cap Head | 8mm | 10 |

<br>

## 19 Inch - Dual:
<p float="center">
   
</p>

#### **Sub-Assemblies:**
| Assembly | Quantity |
| --- | --- |
| [PCB Tray](README.md#pcb-tray) | 2 |
| [IEC Plug](README.md#iec-plug) | 2 |

#### **Housing:**
| Item | File Name | Material | Quantity |
| --- | --- | --- | --- |
| Tray | 19in_Dual-Tray.stp | Sheel Metal | 1 |
| Lid | 19in_Dual-Lid.stp | Sheel Metal | 1 |
| Front-1 | 19in_Dual-Front_1.stl | 3D Print (ABS/ASA) | 1 |
| Front-2 | 19in_Dual-Front_2.stl | 3D Print (ABS/ASA) | 1 |
| Back-1  | 19in_Dual-Back_1.stl  | 3D Print (ABS/ASA) | 1 |
| Back-2  | 19in_Dual-Back_2.stl  | 3D Print (ABS/ASA) | 1 |
| Divider | 19in_Dual-Divider.stl | 3D Print (ABS/ASA) | 3 |
[Housing files are located here](https://github.com/Shrike-Lab/MiniLab-PSU/tree/main/ASSEMBLY/CAD/19in_Dual)

#### **Hardware**
| Item | Length | Quantity |
| --- | --- | --- |
| M3 Low Profile Bolt | 5mm | 42 |
| M3 Plastic Washer | - | 8 |
| M3 Insert | - | 48 |  
| M4 Low Profile Bolt | 5mm | 14 | 
| M3 Cap Head | 8mm | 16 | 

<br>

## 19 Inch - Dual - SBS:
<p float="center">
   
</p>

#### **Sub-Assemblies:**
| Assembly | Quantity |
| --- | --- |
| [PCB Tray](README.md#pcb-tray) | 2 |
| [IEC Plug](README.md#iec-plug) | 2 |

#### **Housing:**
| Item | File Name | Material | Quantity |
| --- | --- | --- | --- |
| Tray | 19in_Dual_SBS-Tray.stp | Sheel Metal | 1 |
| Lid | 19in_Dual_SBS-Lid.stp | Sheel Metal | 1 |
| Front-1 | 19in_Dual_SBS-Front_1.stl  | 3D Print (ABS/ASA) | 1 |
| Front-2 | 19in_Dual_SBS-Front_2.stl | 3D Print (ABS/ASA) | 1 |
| Back-1  | 19in_Dual_SBS-Back_1.stl  | 3D Print (ABS/ASA) | 1 |
| Back-2  | 19in_Dual_SBS-Back_2.stl  | 3D Print (ABS/ASA) | 1 |
| Divider | 19in_Dual_SBS-Divider.stl | 3D Print (ABS/ASA) | 2 |
[Housing files are located here](https://github.com/Shrike-Lab/MiniLab-PSU/tree/main/ASSEMBLY/CAD/19in_Dual_SBS)

#### **Hardware**
| Item | Length | Quantity |
| --- | --- | --- |
| M3 Low Profile Bolt | 5mm | 42 |
| M3 Plastic Washer | - | 8 | 
| M3 Insert | - | 48 | 
| M4 Low Profile Bolt | 5mm | 12 |
| M3 Cap Head | 8mm | 16 |

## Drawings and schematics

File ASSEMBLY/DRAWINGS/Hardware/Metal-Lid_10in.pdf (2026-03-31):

E E

F F

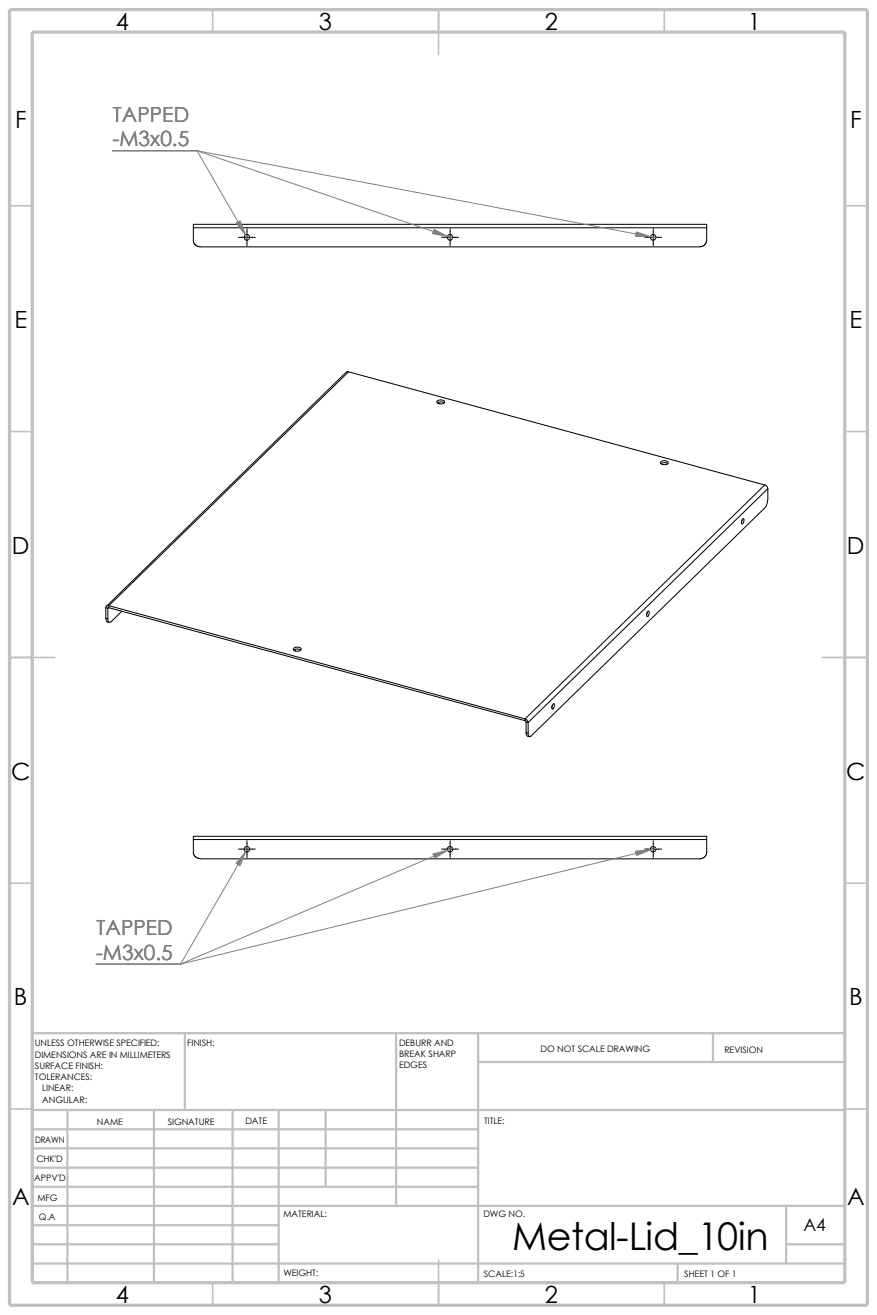
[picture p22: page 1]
TITLE:; SCALE:1:5; SHEET 1 OF 1; WEIGHT:; MATERIAL:; DWG NO.; REVISION; SIGNATURE; DATE DRAWN; MFG; FINISH:; EDGES; NAME; DEBURR AND BREAK SHARP; Metal-Lid_10in; TAPPED -M3x0.5; TAPPED

UNLESS OTHERWISE SPECIFIED:
DIMENSIONS ARE IN MILLIMETERS
SURFACE FINISH:
TOLERANCES:
LINEAR:
ANGULAR:

DO NOT SCALE DRAWING

CHK'D
APPV'D

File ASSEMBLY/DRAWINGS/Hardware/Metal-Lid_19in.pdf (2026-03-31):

E E

F F

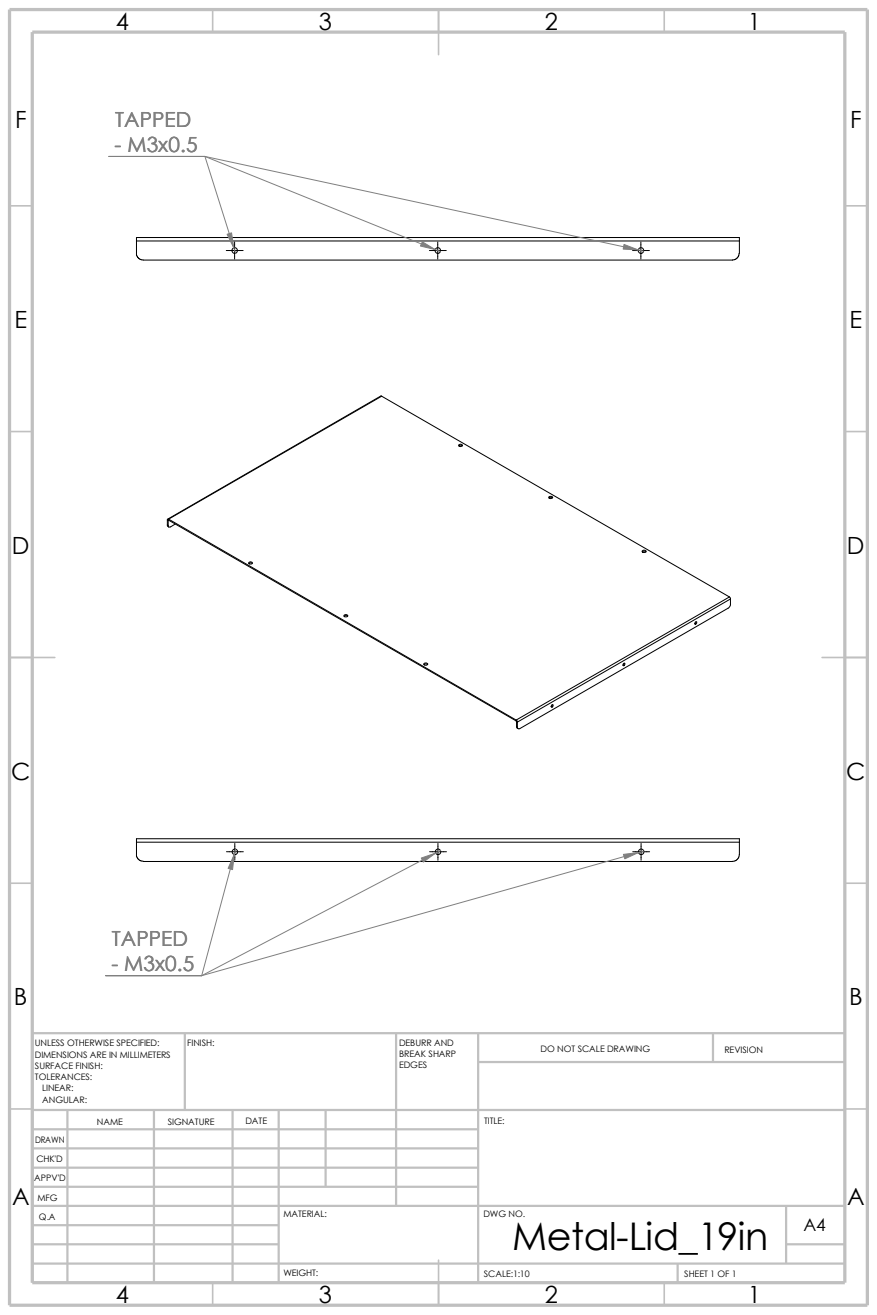
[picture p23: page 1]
DO NOT SCALE DRAWING; REVISION; TITLE:; DWG NO.; SCALE:1:10; SHEET 1 OF 1; WEIGHT:; SIGNATURE; MATERIAL:; NAME; DATE; EDGES; MFG; FINISH:; DEBURR AND BREAK SHARP; Metal-Lid_19in; TAPPED; TAPPED - M3x0.5

UNLESS OTHERWISE SPECIFIED:
DIMENSIONS ARE IN MILLIMETERS
SURFACE FINISH:
TOLERANCES:
LINEAR: DRAWN
ANGULAR:

CHK'D
APPV'D

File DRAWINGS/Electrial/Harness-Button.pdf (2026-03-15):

E E

F F

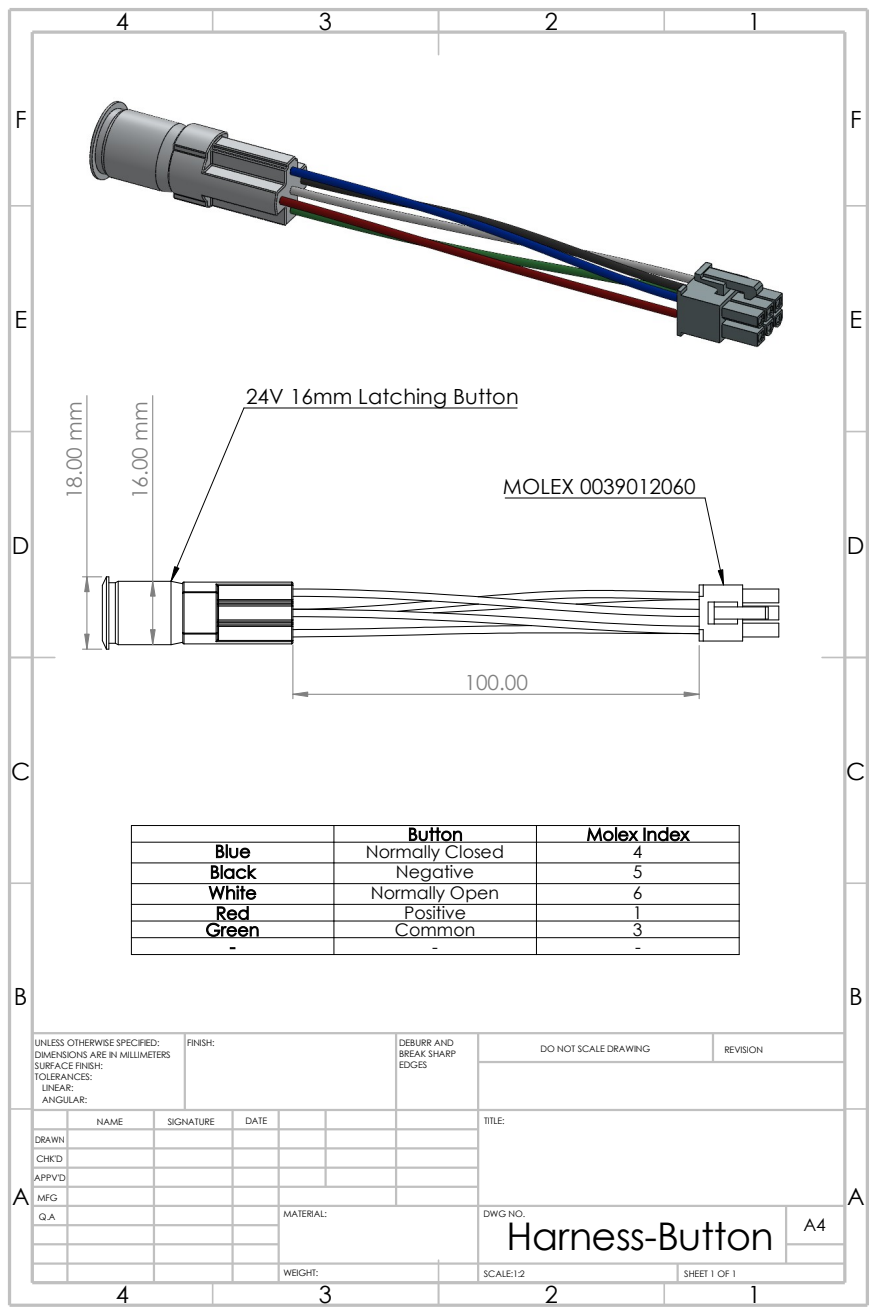
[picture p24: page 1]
MATERIAL:; REVISION; DWG NO.; SCALE:1:2; SHEET 1 OF 1; WEIGHT:; EDGES; FINISH:; MFG; DEBURR AND BREAK SHARP; Harness-Button; MOLEX 0039012060 18.00 mm; 24V 16mm Latching Button

Button | Molex Index

Blue | Normally Closed | 4
Black | Negative | 5
White | Normally Open | 6
Red | Positive | 1
Green | Common | 3

UNLESS OTHERWISE SPECIFIED:
DIMENSIONS ARE IN MILLIMETERS
SURFACE FINISH:
TOLERANCES:
LINEAR:
ANGULAR:

DO NOT SCALE DRAWING

NAME | SIGNATURE | DATE | TITLE:

DRAWN
CHK'D
APPV'D

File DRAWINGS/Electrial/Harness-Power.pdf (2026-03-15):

E E

F F

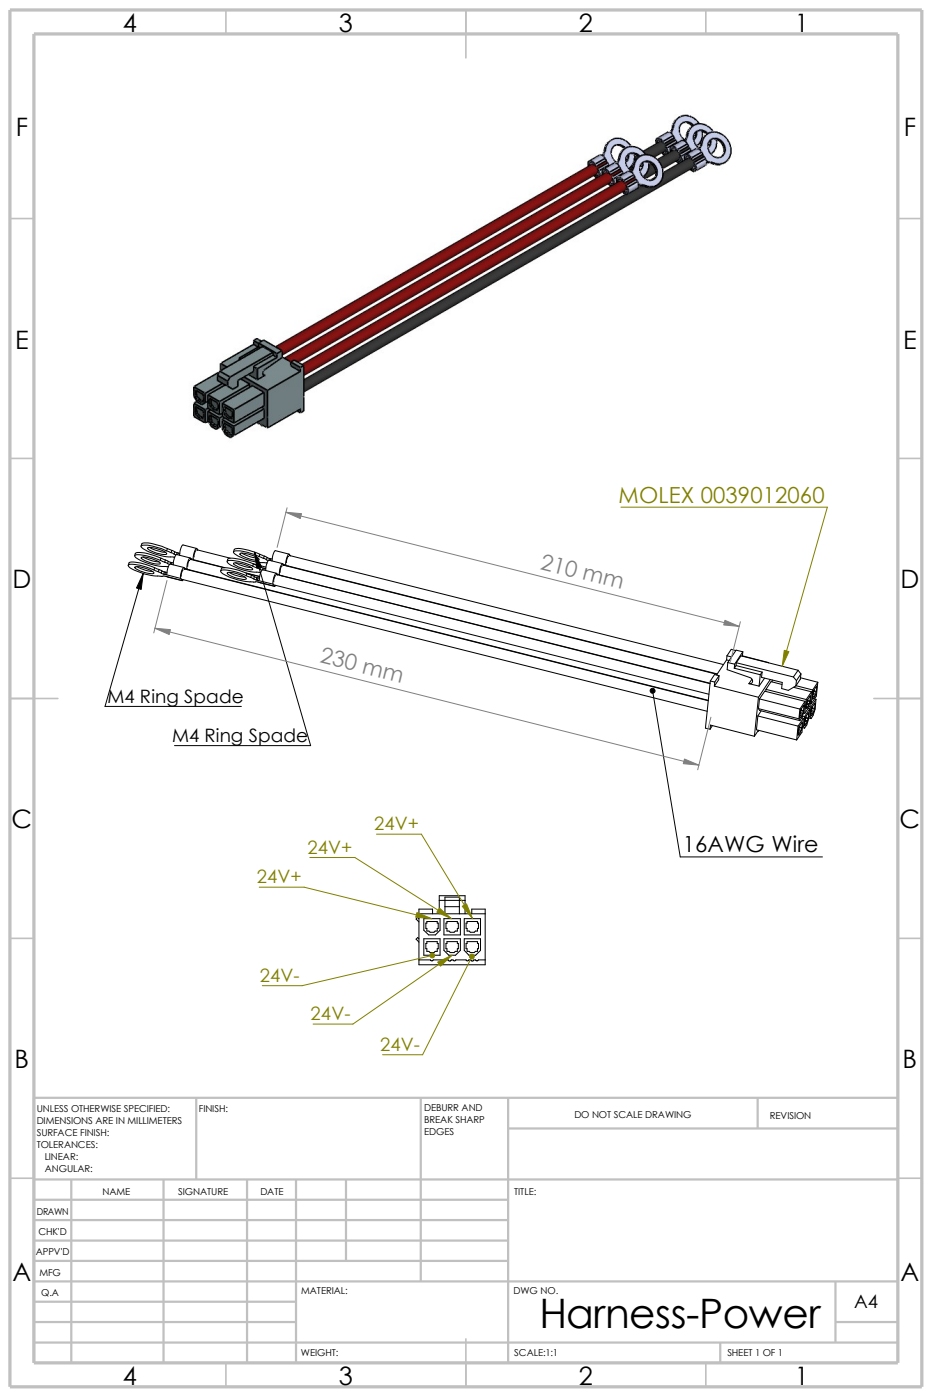
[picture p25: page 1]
DWG NO.; SCALE:1:1; SHEET 1 OF 1; WEIGHT:; DO NOT SCALE DRAWING; REVISION; MATERIAL:; MFG; FINISH:; EDGES; DEBURR AND BREAK SHARP; Harness-Power; MOLEX 0039012060; M4 Ring Spade; 16AWG Wire

UNLESS OTHERWISE SPECIFIED:
DIMENSIONS ARE IN MILLIMETERS
SURFACE FINISH:
TOLERANCES:
LINEAR:
ANGULAR:

NAME | SIGNATURE | DATE | TITLE:

DRAWN
CHK'D
APPV'D

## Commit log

2026-01-07 Updating RM
    [1U Minilab PSU.csv, 1U Minilab PSU.kicad_pcb, 1U Minilab PSU.kicad_sch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]
2026-03-31 PCB readme
2026-04-01 added stl exports
    [10in_3D-Back.stl, 10in_3D-Bottom_1.stl, 10in_3D-Bottom_2.stl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]
2026-04-04 Added 10in DXF and PCB BOM and positions
    [Metal_Lid-Short.DXF, Metal_Tray_Dual.DXF, bom.csv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]
2026-04-04 Added reinforcement bracket
    [Reinforcement_Bracket.STL]
2026-04-05 Button wiring note
2026-04-07 Added STEP files for unibody variant
    [10in_Uni-Body.STEP, 10in_Uni-SidePanel.STEP, 10in_Uni-Tray.STEP]
2026-04-14 Added flipped variants to modular 10 in
    [10in_3D-Back-FLIPPED.STL, 10in_3D-Front-FLIPPED.STL]
2026-04-19 Added assembly bracket
    [Assembly_Bracket.STL]
2026-05-03 Small updates to PCB
    [HomeLab-PSU-V1_BOM.csv, HomeLab-PSU-V1_positions.csv, bom.csv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]
